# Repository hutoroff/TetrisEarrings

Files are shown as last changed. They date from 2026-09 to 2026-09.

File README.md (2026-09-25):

# ✨ TetrisEarrings

Earrings built on a 6×10 LED matrix with nine mesmerizing animated modes — from ping-pong and Tetris with an autonomous bot to fire, a starry sky, and rain on glass.







<p align="center">
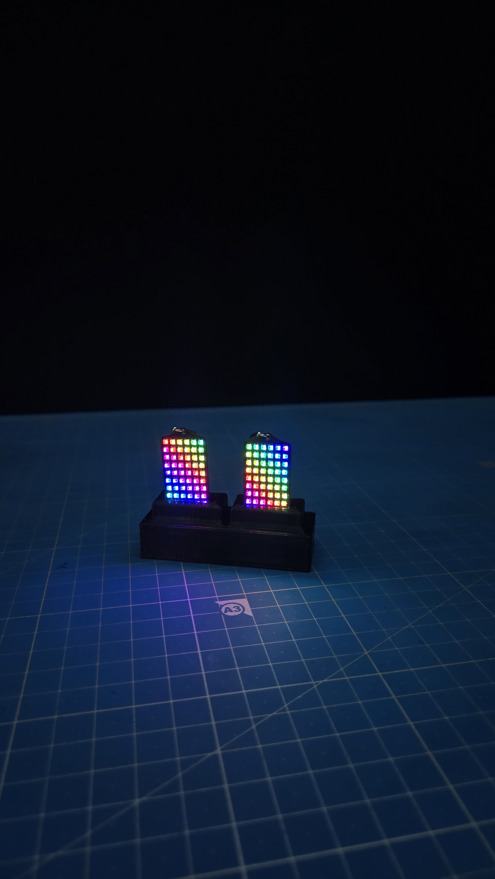
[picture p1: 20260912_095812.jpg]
TetrisEarrings in action
  
</p>

## About

A tiny STM32 board hidden inside the earring drives a matrix of 60 addressable RGB LEDs (6 columns × 10 rows). A single button switches modes manually, or they cycle on their own every 45 seconds. The device runs on a battery and can power itself off — either on a long button press or when the battery runs low — with a short farewell animation.

## Features

- 🎮 **9 modes** — from classic games to generative visual effects
- 🧠 **Tetris with a "smart" bot** — pieces don't just fall randomly: before each drop the bot tries every rotation and column and picks the placement using a heuristic (fewest holes, lowest height and bumpiness, most cleared lines)
- 🐍 **Snake with an autonomous bot** — finds its own path to the food and never runs into itself
- 🎨 **Sub-pixel smoothing** — the ping-pong balls move smoothly instead of jumping from LED to LED
- 🔋 **Smart power management** — continuous battery voltage monitoring and automatic shutdown on low battery
- 📺 **Power-off animation** — the screen "collapses" into a dot and fades out, like an old CRT TV
- 🧩 **Everything in 6 KB of RAM** — all modes share the same memory region (a union) instead of each mode keeping its own data

## Modes

| # | Mode | Description |
|---|---|---|
| 0 | Ping-Pong | Three balls fly around and bounce off each other, changing color on impact |
| 1 | Tetris | Autonomous game with a bot that deliberately chooses where to place each piece |
| 2 | Snake | Autonomous game; the bot steers the snake to the food by itself |
| 3 | Heart | A smoothly pulsing heart |
| 4 | Fire | Procedural simulation of a living flame with sparks |
| 5 | Matrix | Falling green "digital rain" in the style of *The Matrix* |
| 6 | Starry Sky | Sparse twinkling stars of different hues that slowly fade out |
| 7 | Rainbow | A shimmering diagonal rainbow wave |
| 8 | Rain on Glass | Drops trickle down and burst into splashes when they hit the bottom |

Short button press — next mode; hold for about a second — power off (with animation). With no presses, modes cycle automatically every 45 seconds.

## Hardware

| Parameter | Value |
|---|---|
| Microcontroller | STM32F070F6Px (Cortex-M0, 48 MHz, 32 KB Flash, 6 KB RAM) |
| Matrix | 6×10 (60 pcs) addressable RGB LEDs, WS2812-compatible protocol |
| Matrix data line | PA9 (TIM1_CH2 + DMA, per-bit PWM signal encoding) |
| Button | PA7 |
| Power control | PA6 (board power self-latch / shutdown) |
| Battery monitoring | PA1 (ADC1_IN1), auto-shutdown on low battery |
| Development environment | STM32CubeIDE 1.17.0, GNU Arm Embedded Toolchain 12.3.rel1 |

The matrix LEDs are wired in a "serpentine" layout: even rows run in one direction, odd rows in the other (see `GetLEDIndex()` in [ledMatrix.c](Core/Src/ledMatrix.c)).

### Power

1S Li-Po → P-MOSFET soft latch (button turns it on, PA6 holds it, PA6 low = off) → switched rail `VSW`. The LEDs run straight from `VSW` (3.5–4.2 V); the MCU gets 3.3 V from an LDO. Battery voltage is sensed on PA1 through a 62k/100k divider, so the firmware's 2700-count threshold means a **3.52 V** cutoff. Charging: MCP73831 at ~150 mA from two dock pads (the printed stand). Average draw ≈ 55–60 mA (mostly WS2812 idle current), so a 300 mAh 602030 cell gives ≈ 4.5 h.

### Components

| Qty | Ref | Part | Package | Note |
|---|---|---|---|---|
| 1 | U1 | STM32F070F6P6 | TSSOP-20 | MCU |
| 60 | LED1–LED60 | WS2812B-2020 | 2020 PLCC-4 | 6×10 matrix |
| 1 | U2 | MCP73831T-2ACI/OT | SOT-23-5 | Li-Po charger 4.2 V |
| 1 | U3 | ME6211C33M5G | SOT-23 | 3.3 V LDO |
| 1 | Q1 | AO3401A | SOT-23 | P-MOSFET power switch |
| 1 | Q2 | 2N7002 | SOT-23 | Latch driver |
| 2 | D1, D2 | BAT54W | SOD-323 | Latch OR diodes |
| 1 | D3 | LED red | 0603 | Charge indicator |
| 1 | Y1 | 8 MHz crystal | 3225 | HSE |
| 1 | SW1 | Tactile switch | SMD | Mode / power button |
| 1 | BT1 | Li-Po 1S 602030 300 mAh | 2 pads | With PCM; 602535 400 mAh for more runtime |
| — | J1 | TC2030-IDC-NL footprint | Tag-Connect pads | SWD; bare copper, nothing to buy |
| — | J2 | Dock contacts | 2 pads | 5 V charging; bare copper, nothing to buy |
| 5 | R1, R2, R3, R5, R8 | 100k | 0402 | Pull-ups/downs, dividers |
| 1 | R4 | 33k | 0402 | Button divider |
| 1 | R6 | 330 Ω | 0402 | LED data series |
| 1 | R7 | 62k | 0402 | Battery divider (cutoff) |
| 1 | R9 | 6.8k | 0402 | Charge current |
| 1 | R10 | 1k | 0402 | Charge LED |
| 1 | R11 | 10k | 0402 | BOOT0 |
| 13 | C5, C7, C8, C13–C22 | 100 nF | 0402 | Decoupling, NRST, LED rows |
| 3 | C3, C4, C6 | 1 µF | 0402 | LDO in/out, VDD |
| 2 | C9, C10 | 12 pF | 0402 | Crystal load |
| 1 | C11 | 10 nF | 0402 | ADC filter |
| 2 | C1, C2 | 4.7 µF | 0603 | Charger in/out |
| 1 | C12 | 10 µF | 0603 | LED rail bulk |

Total: 104 purchased components (24 BOM lines) plus 2 copper-pad footprints. Machine-readable list: [hardware/BOM.csv](hardware/BOM.csv).

## Electronics (Altium)

Schematic, PCB and BOM live in [`hardware/`](hardware/) as a KiCad project (text, generated by `gen_schematic.py` / `gen_pcb.py`). The PCB is 24 × 48 mm, 4 layers: the LEDs are on the front, everything else is on the back, and the inner layers are GND and VSW planes. It is fully routed, with DRC 0 errors and 0 differences from the schematic. Ready-to-upload JLCPCB files are in [`hardware/fab/`](hardware/fab/).

Altium Designer 21+ opens it directly: **File → Import Wizard → KiCad Design Files** → select the `hardware/` folder → Finish → **Project → Compile**. Circuit description, layout notes and tuning knobs (battery cutoff, charge current, battery size) are in [hardware/README.md](hardware/README.md).

## Building and Flashing

1. Clone the repository and open the project folder in **STM32CubeIDE 1.17.0** (File → Import → General → Existing Projects into Workspace).
2. Choose a build configuration:
   - **Debug** — full debug symbols, `-Og` optimization (chosen specifically so the firmware fits into the chip's 32 KB of flash while still being easy to debug);
   - **Release** — `-Os` build, minimal size.
3. **Project → Build Project**.
4. Flash via ST-Link: **Run → Debug** (or **Run**) with the programmer connected.

## Project Structure

```
Core/
├── Inc/                  # Headers
│   ├── effects.h          # Visual effects
│   ├── games.h            # Tetris and Snake
│   ├── ledMatrix.h        # WS2812 driver
│   └── saportAndData.h    # Shared state (pins, shared mode memory)
└── Src/
    ├── main.c              # Entry point, peripheral initialization
    ├── work.c               # Mode dispatcher, button, ADC, auto-shutdown
    ├── effects.c             # Ping-Pong, Fire, Matrix, Stars, Rainbow, Rain, Heart
    ├── games.c               # Tetris (with AI bot) and Snake (with autonomous bot)
    └── ledMatrix.c            # Addressable matrix driver on top of TIM1 + DMA
```

## License

This project is distributed under the [MIT](LICENSE) license.

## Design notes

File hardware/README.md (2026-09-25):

# TetrisEarrings — electronics

KiCad project generated by scripts; Altium Designer imports it natively.

| File | What |
|---|---|
| `TetrisEarrings.kicad_sch` / `.kicad_pro` | Schematic (single A2 sheet, all symbols embedded) |
| `TetrisEarrings.kicad_pcb` | PCB, 24 × 48 × 0.8 mm, 4 layers, fully routed |
| `TetrisEarrings.pretty/`, `fp-lib-table`, `sym-lib-table`, `.kicad_sym` | Project libraries (the two pad footprints; everything else is KiCad stock) |
| `BOM.csv` | Bill of materials, grouped by value/package |
| `fab/` | JLCPCB upload: Gerber+drill zip, BOM, CPL (pick-and-place) |
| `gen_schematic.py` | Schematic + BOM generator (Python 3, stdlib) |
| `gen_pcb.py` | Placement, fixed front copper, plane fanout (Python 3 + KiCad footprint libs) |
| `route.py` | Autorouting of the back-side signals with Freerouting (run with KiCad's Python) |
| `export_fab.py` | Gerbers, drill, BOM, CPL → `fab/` |

## Regenerate

```sh
python3 hardware/gen_schematic.py        # schematic + BOM
python3 hardware/gen_pcb.py              # board: placement, LED copper, fanout vias (unrouted signals)
/Applications/KiCad/KiCad.app/Contents/Frameworks/Python.framework/Versions/Current/bin/python3 hardware/route.py
python3 hardware/export_fab.py           # fab/ outputs
kicad-cli pcb drc --refill-zones --schematic-parity hardware/TetrisEarrings.kicad_pcb
```

`route.py` needs Java 17+ and `freerouting-1.9.0.jar` in `~/.cache/freerouting/fr-1.9.0.jar` (github.com/freerouting/freerouting/releases). A small Freerouting window appears while it routes. Freerouting 2.x ignores the pass limit in headless mode and never saves its result. Hand edits made in KiCad/Altium are lost on regeneration: either keep changing the scripts, or stop regenerating and treat the `.kicad_pcb` as the source from then on.

## Open in Altium Designer

1. **File → Import Wizard → KiCad Design Files** (Altium 21 or newer).
2. Add the `hardware/` folder (or the `.kicad_pro`), Next through the defaults, Finish.
3. Altium creates `TetrisEarrings.PrjPcb` with one `.SchDoc`. Run **Project → Compile** — it should report no errors; the sheet uses power ports and net labels on pin stubs, which the importer maps 1:1.
4. Optional: `kicad-cli sch export pdf TetrisEarrings.kicad_sch` for a PDF, or open in free KiCad.

## Circuit

**Power.** 1S Li-Po (602030, 300 mAh, with PCM) → `VBAT`. P-MOSFET Q1 (AO3401A) is the high-side switch producing the switched rail `VSW`, which feeds the LEDs directly (3.5–4.2 V, inside WS2812B-2020 spec) and the 3.3 V LDO U3 (ME6211) for the MCU.

**Soft latch** (matches `work.c`). Q1 gate is pulled to `VBAT` by R1 (off). Q2 (2N7002) pulls it low when `LATCH` is high; `LATCH` is the OR of the button (`KEY` via D1) and PA6 (`PWR_ON` via D2), R2 pull-down. Sequence: press → Q2 → Q1 → LDO → MCU boots, reads the button HIGH, sets PA6 = 1 → latch holds after release. PA6 = 0 (long press or low battery) → power drops; firmware spins in `while(1)` waiting for it.

**Button.** SW1 between `VBAT` and `KEY`, R3 100k pull-down (PA7 has no internal pull, pressed = HIGH). `KEY` → PA7 through R4 33k / R5 100k = 0.75·VBAT: 3.16 V at 4.2 V (≤ VDDA + 0.3), 2.6 V at 3.5 V (≥ 0.7·VDD).

**Battery sense.** R7 62k / R8 100k from `VSW` to PA1 (ADC_IN1), C11 filter. Firmware cutoff is 2700/4096 · 3.3 V = 2.175 V → **3.52 V** battery. On `VSW`, so no drain when off. Tune R7: 68k → 3.65 V, 56k → 3.39 V.

**Charger.** MCP73831-2 (4.2 V), input from two dock pads J2 (`VCHG` 5 V, GND — the printed stand acts as the dock), R9 6.8k → ~150 mA (0.5 C), D3 charge indicator. The charger connects straight to the battery, so charging works with the earring off.

**LEDs.** 60 × WS2812B-2020, DIN of LED1 from PA9 (TIM1_CH2) via R6 330 Ω. Chain order equals the firmware index from `GetLEDIndex()`: row 0 is the bottom row, even rows run right→left, odd rows left→right; LED*n* has index *n*−1. C12 10 µF bulk plus one 100 nF per row (C13–C22).

**MCU.** STM32F070F6P6 TSSOP-20, 8 MHz crystal Y1 with 12 pF loads (`ponytail:` set to the crystal's CL), BOOT0 10k to GND, NRST 100 nF, SWD via Tag-Connect TC2030 pads (J1). PA0, PA2–PA5, PA10, PB1 unused; PA3/PA4 (`Led1`/`Led2` in the `.ioc`) are initialised by firmware but never driven, so they are left unconnected.

## PCB layout

**Stackup** (JLC 4-layer, 0.8 mm):

| Layer | Contents |
|---|---|
| F.Cu | LEDs, data chain, power rails |
| In1 | GND plane |
| In2 | VSW plane |
| B.Cu | all other parts and signal routing |

The rules are the JLC standard: 0.15 mm track and clearance, 0.45/0.2 mm vias, 0.3 mm copper-to-edge.

**Front (jewellery face).**
- The LEDs sit on a 3.5 mm grid, and odd rows are rotated 180° so each DOUT→DIN hop is a short jog.
- Each gap between rows carries one power rail, alternating VSW and GND. Each rail hugs the row below it, which leaves a band where signal vias fit.
- The rails reach the planes only through vias in the board-edge strips (GND on the left, VSW on the right). This keeps the back free of a via grid.
- There is no silkscreen on the front, and there are 2 dock pads at the bottom edge.

**Back.**
- MCU in the middle, with the crystal right against PF0/PF1.
- Soft-latch parts near the top, and the button at the top edge so it stays accessible.
- Charger at the bottom, next to the Tag-Connect footprint (it has 3 NPTH alignment holes).
- Battery pads on the left edge. Glue the 602030 pouch over the back parts with kapton tape in between; the button and SWD pads stay uncovered.
- Every back-side GND/VSW pad has its own fanout via to its plane.
- 0.8 mm earring-hook hole at the top.

**Assembly.**
- JLC assembles both sides from `fab/`.
- BT1 is excluded from the CPL; solder the pouch tabs by hand.
- J1/J2 are bare copper.
- JLC's CPL preview sometimes shows parts rotated (a known library-orientation quirk, typically on SOT-23 and TSSOP). Check the rotation preview on the order page before paying.

## Power budget / battery choice

WS2812B-2020 idle current ≈ 0.6–0.7 mA each → ~40 mA for 60 LEDs, MCU ≈ 8 mA, lit-LED average ≈ 8 mA (effects stay ≤ ~25 % per channel) → **≈ 55–60 mA**. 300 mAh usable to 3.5 V ≈ 4.5 h. For more margin use 602535 (400 mAh, ≈ 6 h) — same pads, BOM change only.

Footprints `TetrisEarrings:Pad_Battery_2x` and `Pad_Dock_2x` are placeholders for two solder pads each; draw them to the pad/contact geometry of your dock.

## Verification (KiCad 10.0.6)

- `kicad-cli sch erc`: 0 errors, 0 warnings.
- `kicad-cli pcb drc --refill-zones --schematic-parity`: 0 errors, 0 unconnected items, 0 schematic-parity issues.
- The only warnings are 61 "footprint differs from library":
  - 60 are the LEDs, whose front silkscreen was removed on purpose.
  - 1 is the Tag-Connect footprint mirrored to the back.
- `TetrisEarrings.pdf` is the rendered schematic.

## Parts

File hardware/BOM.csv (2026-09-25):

Refs | Qty | Value | Package | MPN | Description
BT1 | 1 | LiPo 300mAh | Pad_Battery_2x |  | 1S Li-Po 602030 (6x20x30 mm) with PCM, solder pads
C1, C2 | 2 | 4.7u | C_0603_1608Metric |  | Charger input; Charger output / battery
C3, C4, C6 | 3 | 1u | C_0402_1005Metric |  | LDO input; LDO output; VDD bulk
C5, C7, C8, C13, C14, C15, C16, C17, C18, C19, C20, C21, C22 | 13 | 100n | C_0402_1005Metric |  | VDD decoupling; VDDA decoupling; NRST filter; LED row decoupling
C9, C10 | 2 | 12p | C_0402_1005Metric |  | Crystal load
C11 | 1 | 10n | C_0402_1005Metric |  | ADC filter
C12 | 1 | 10u | C_0603_1608Metric |  | LED rail bulk
D1, D2 | 2 | BAT54 | D_SOD-323 | BAT54W | Button -> latch OR; PA6 -> latch OR
D3 | 1 | RED | LED_0603_1608Metric |  | Charging indicator
LED1-LED60 | 60 | WS2812B-2020 | LED_WS2812B-2020_PLCC4_2.0x2.0mm | WS2812B-2020 | Addressable RGB LED 2x2 mm
Q1 | 1 | AO3401A | SOT-23 | AO3401A | High-side P-MOSFET switch
Q2 | 1 | 2N7002 | SOT-23 | 2N7002 | Latch driver
R1, R2, R3, R5, R8 | 5 | 100k | R_0402_1005Metric |  | Q1 gate pull-up (off); Latch pull-down; Button pull-down; Battery divider bottom; Button divider bottom
R4 | 1 | 33k | R_0402_1005Metric |  | Button divider top
R6 | 1 | 330 | R_0402_1005Metric |  | LED data series
R7 | 1 | 62k | R_0402_1005Metric |  | Battery divider top (sets 3.52 V cutoff)
R9 | 1 | 6.8k | R_0402_1005Metric |  | Charge current 1000V/R = 147 mA
R10 | 1 | 1k | R_0402_1005Metric |  | Charge LED series
R11 | 1 | 10k | R_0402_1005Metric |  | BOOT0 pull-down
SW1 | 1 | BTN | SW_Push_1P1T_NO_CK_KMR2 |  | Tactile button (mode / power)
U1 | 1 | STM32F070F6P6 | TSSOP-20_4.4x6.5mm_P0.65mm | STM32F070F6P6 | Cortex-M0 MCU, TSSOP-20
U2 | 1 | MCP73831-2 | SOT-23-5 | MCP73831T-2ACI/OT | Li-Po charger 4.2 V, ~150 mA
U3 | 1 | ME6211C33 | SOT-23 | ME6211C33M5G-N | 3.3 V LDO, low dropout
Y1 | 1 | 8MHz | Crystal_SMD_3225-4Pin_3.2x2.5mm |  | HSE 8 MHz, 3225

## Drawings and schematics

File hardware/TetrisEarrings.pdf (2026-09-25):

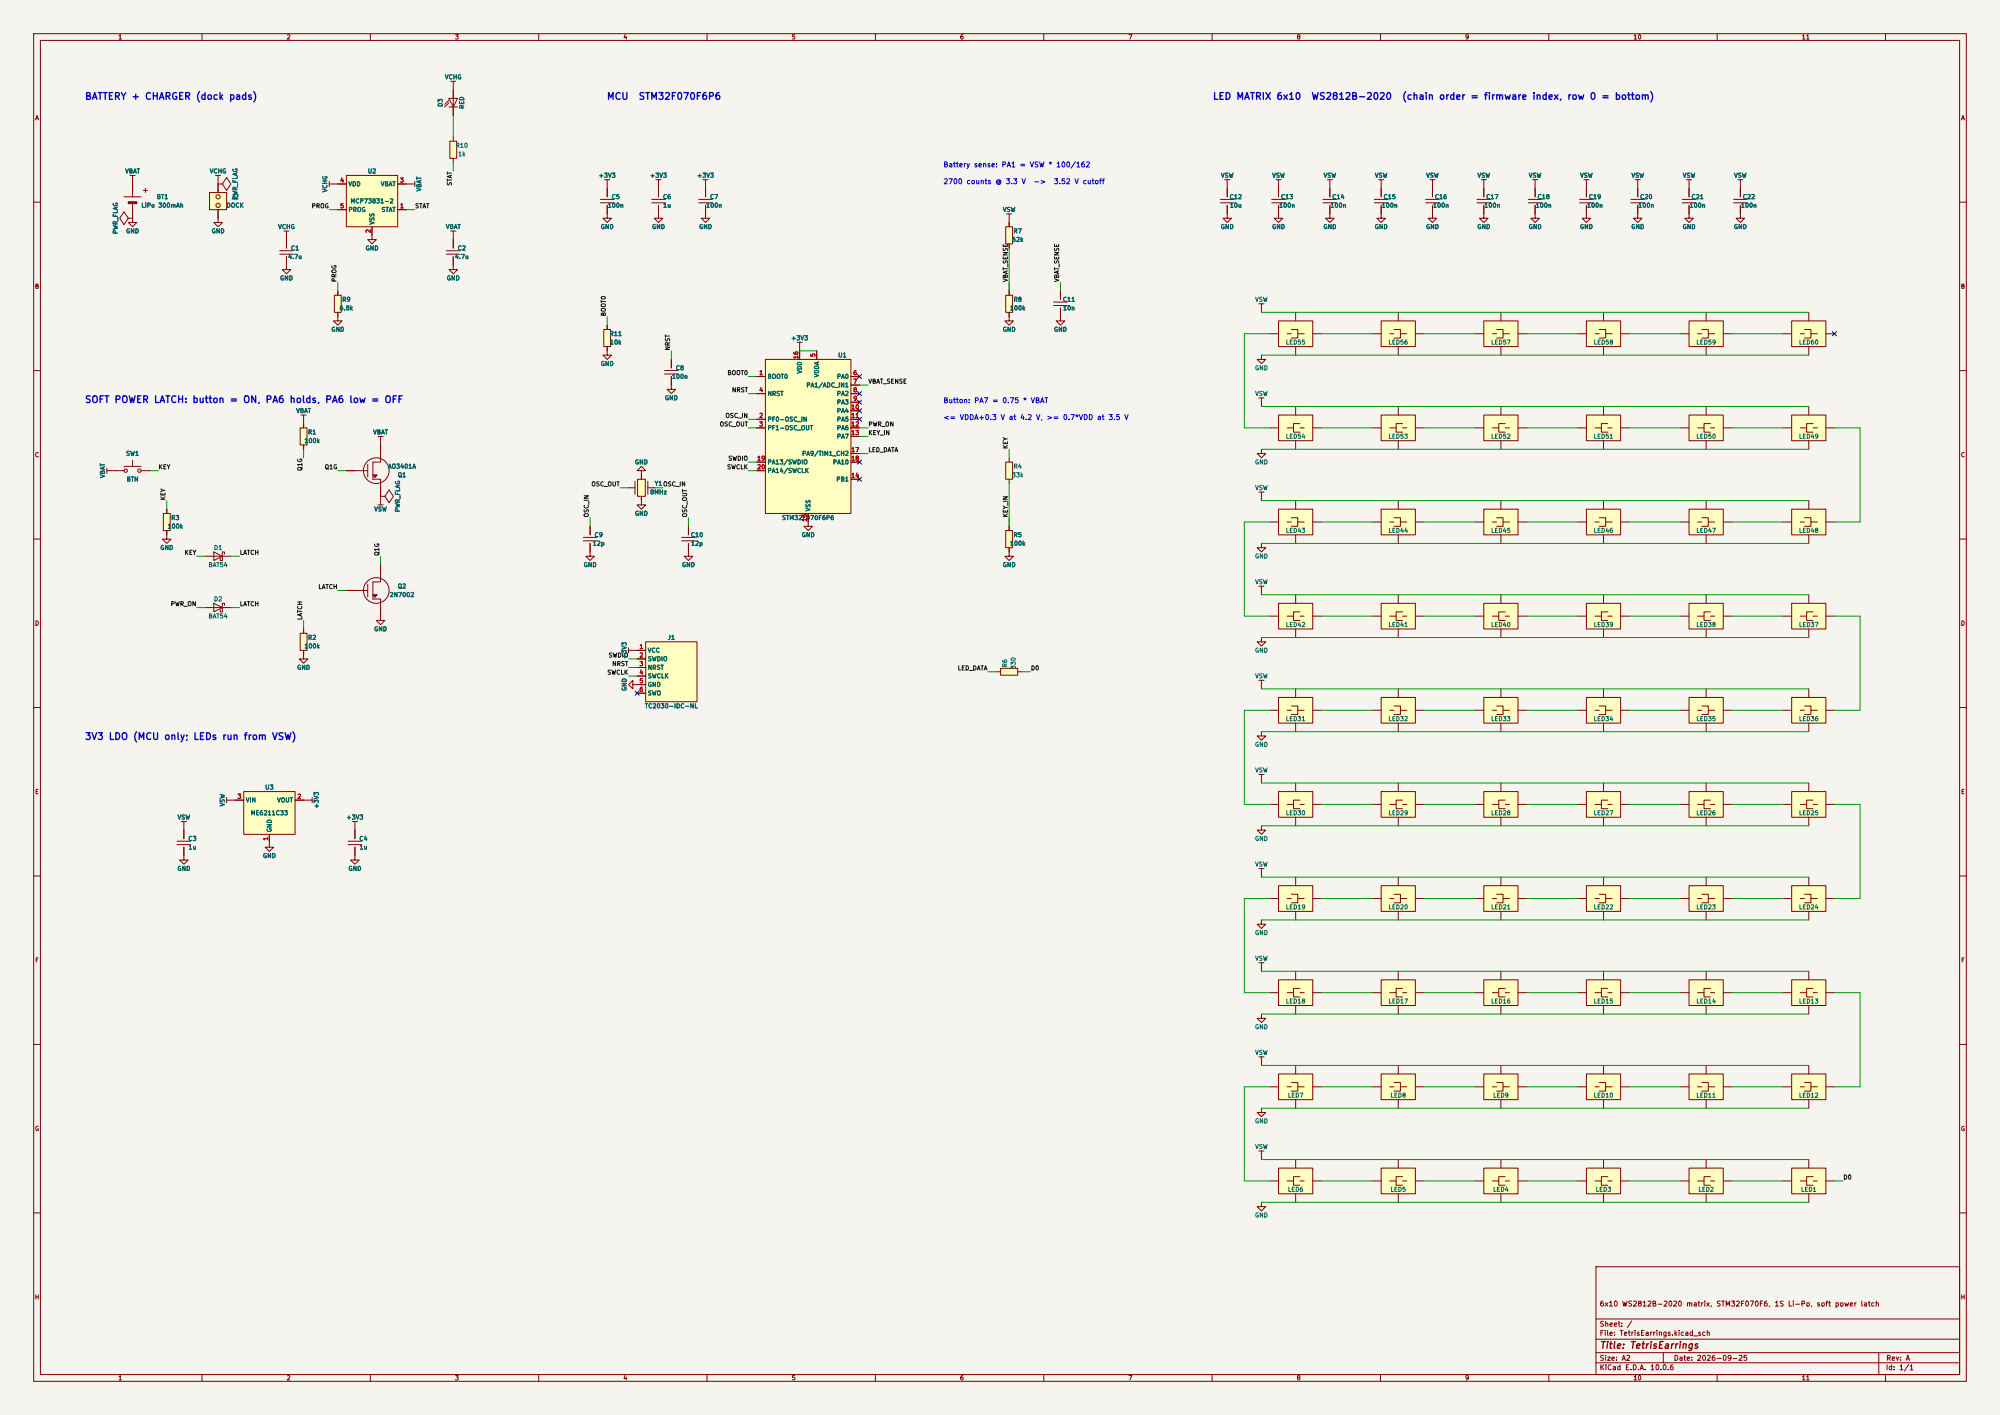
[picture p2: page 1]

SOFT POWER LATCH: button = ON, PA6 holds, PA6 low = OFF

6x10 WS2812B-2020 matrix, STM32F070F6, 1S Li-Po, soft power latch

Size: A2 | Rev: A
KiCad E.D.A. 10.0.6 | Id: 1/1

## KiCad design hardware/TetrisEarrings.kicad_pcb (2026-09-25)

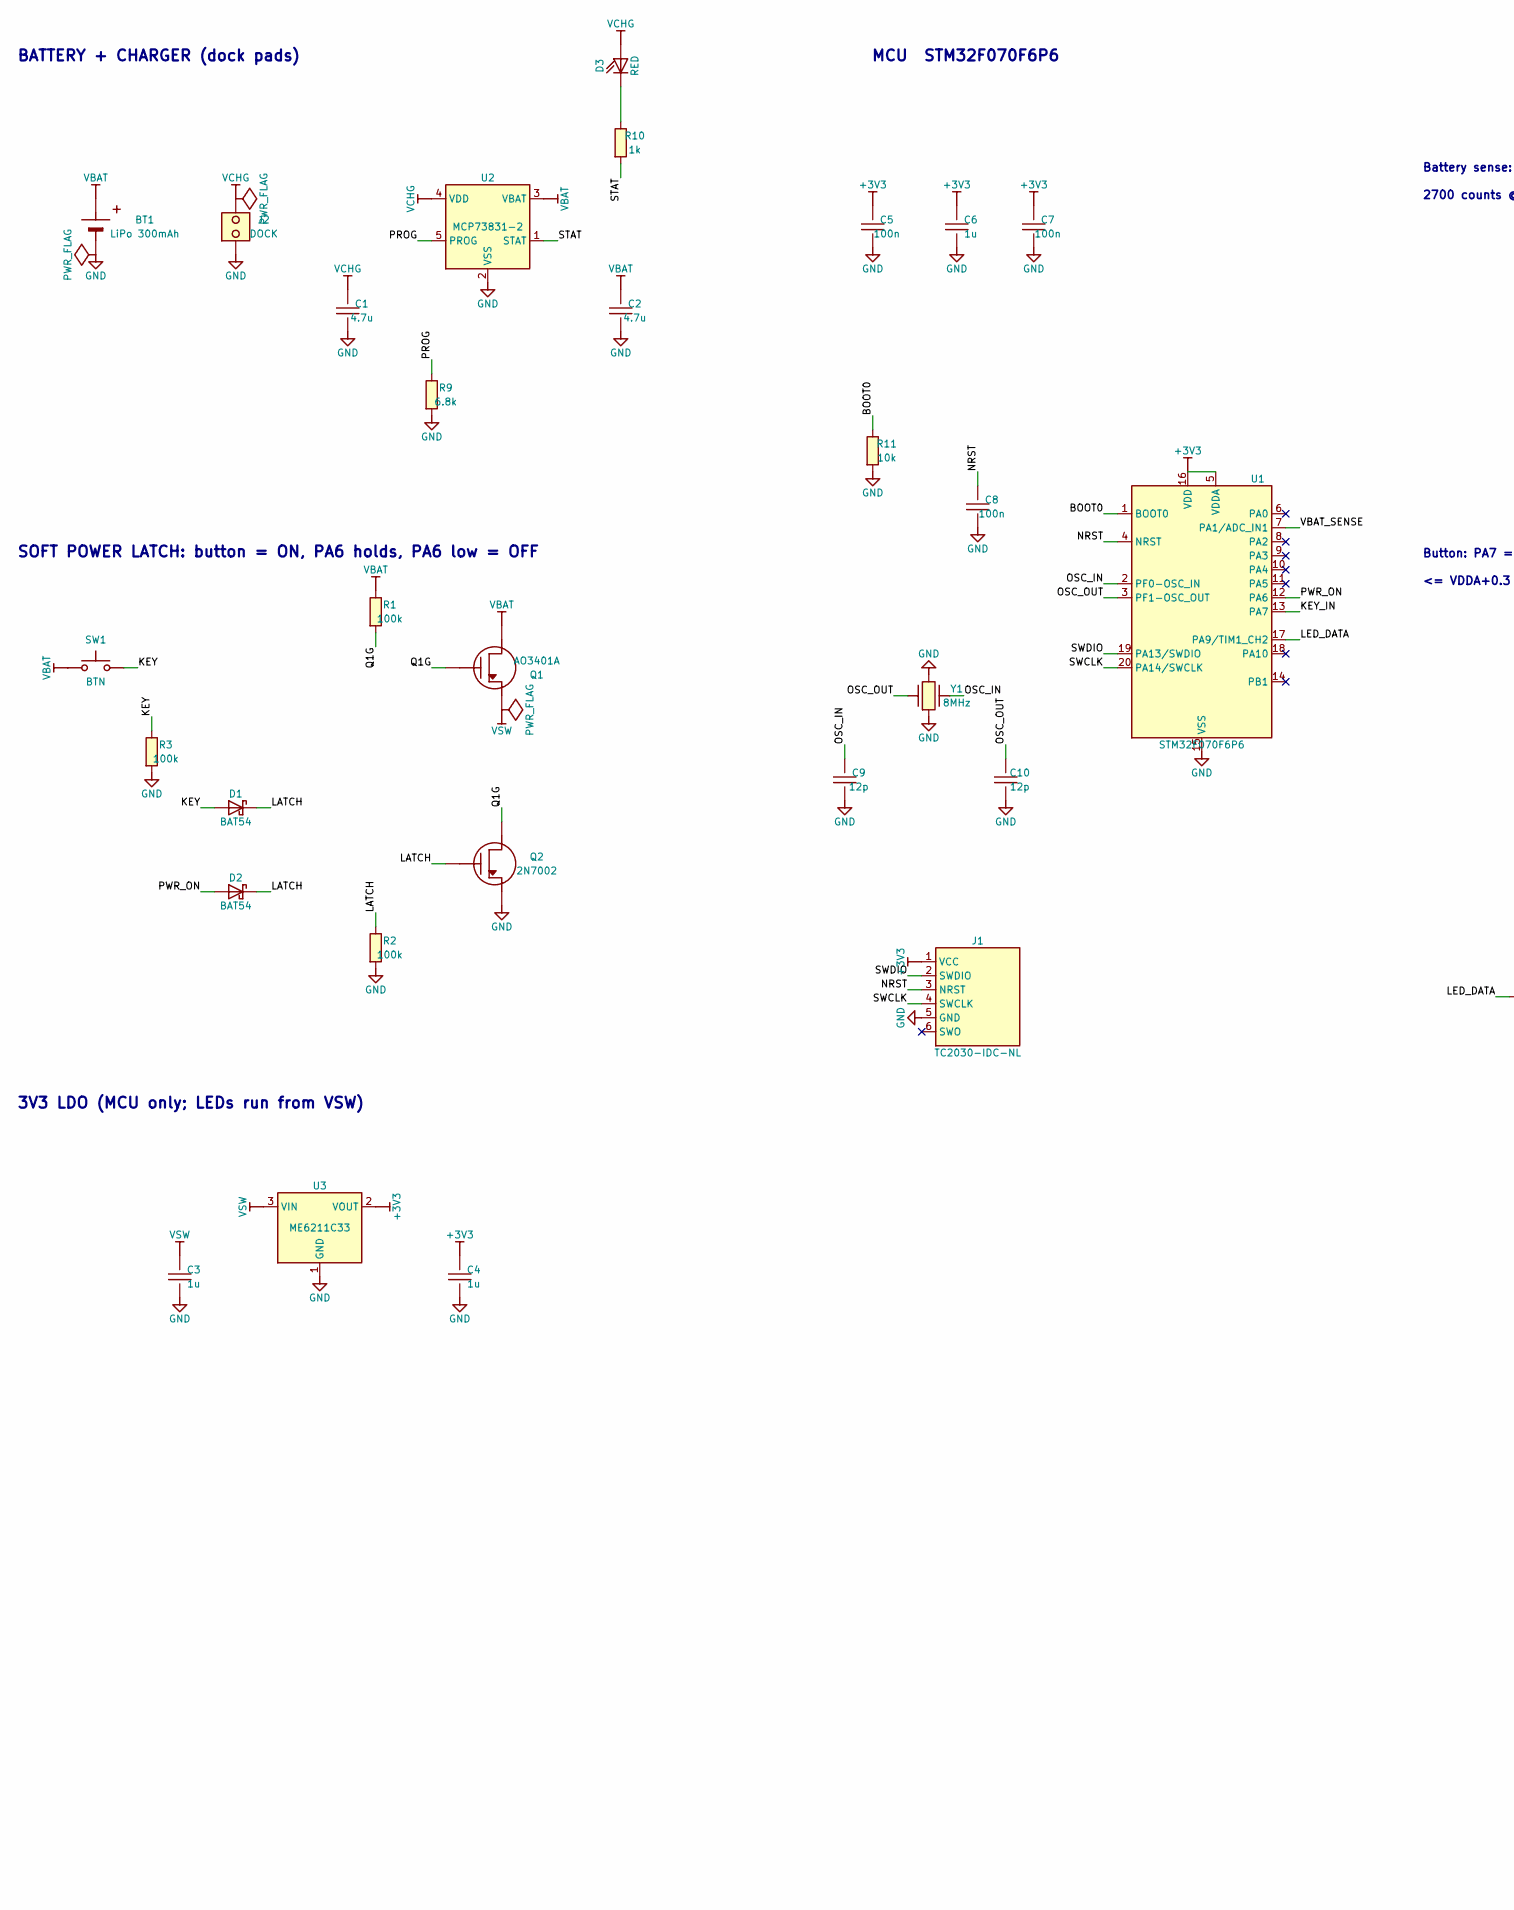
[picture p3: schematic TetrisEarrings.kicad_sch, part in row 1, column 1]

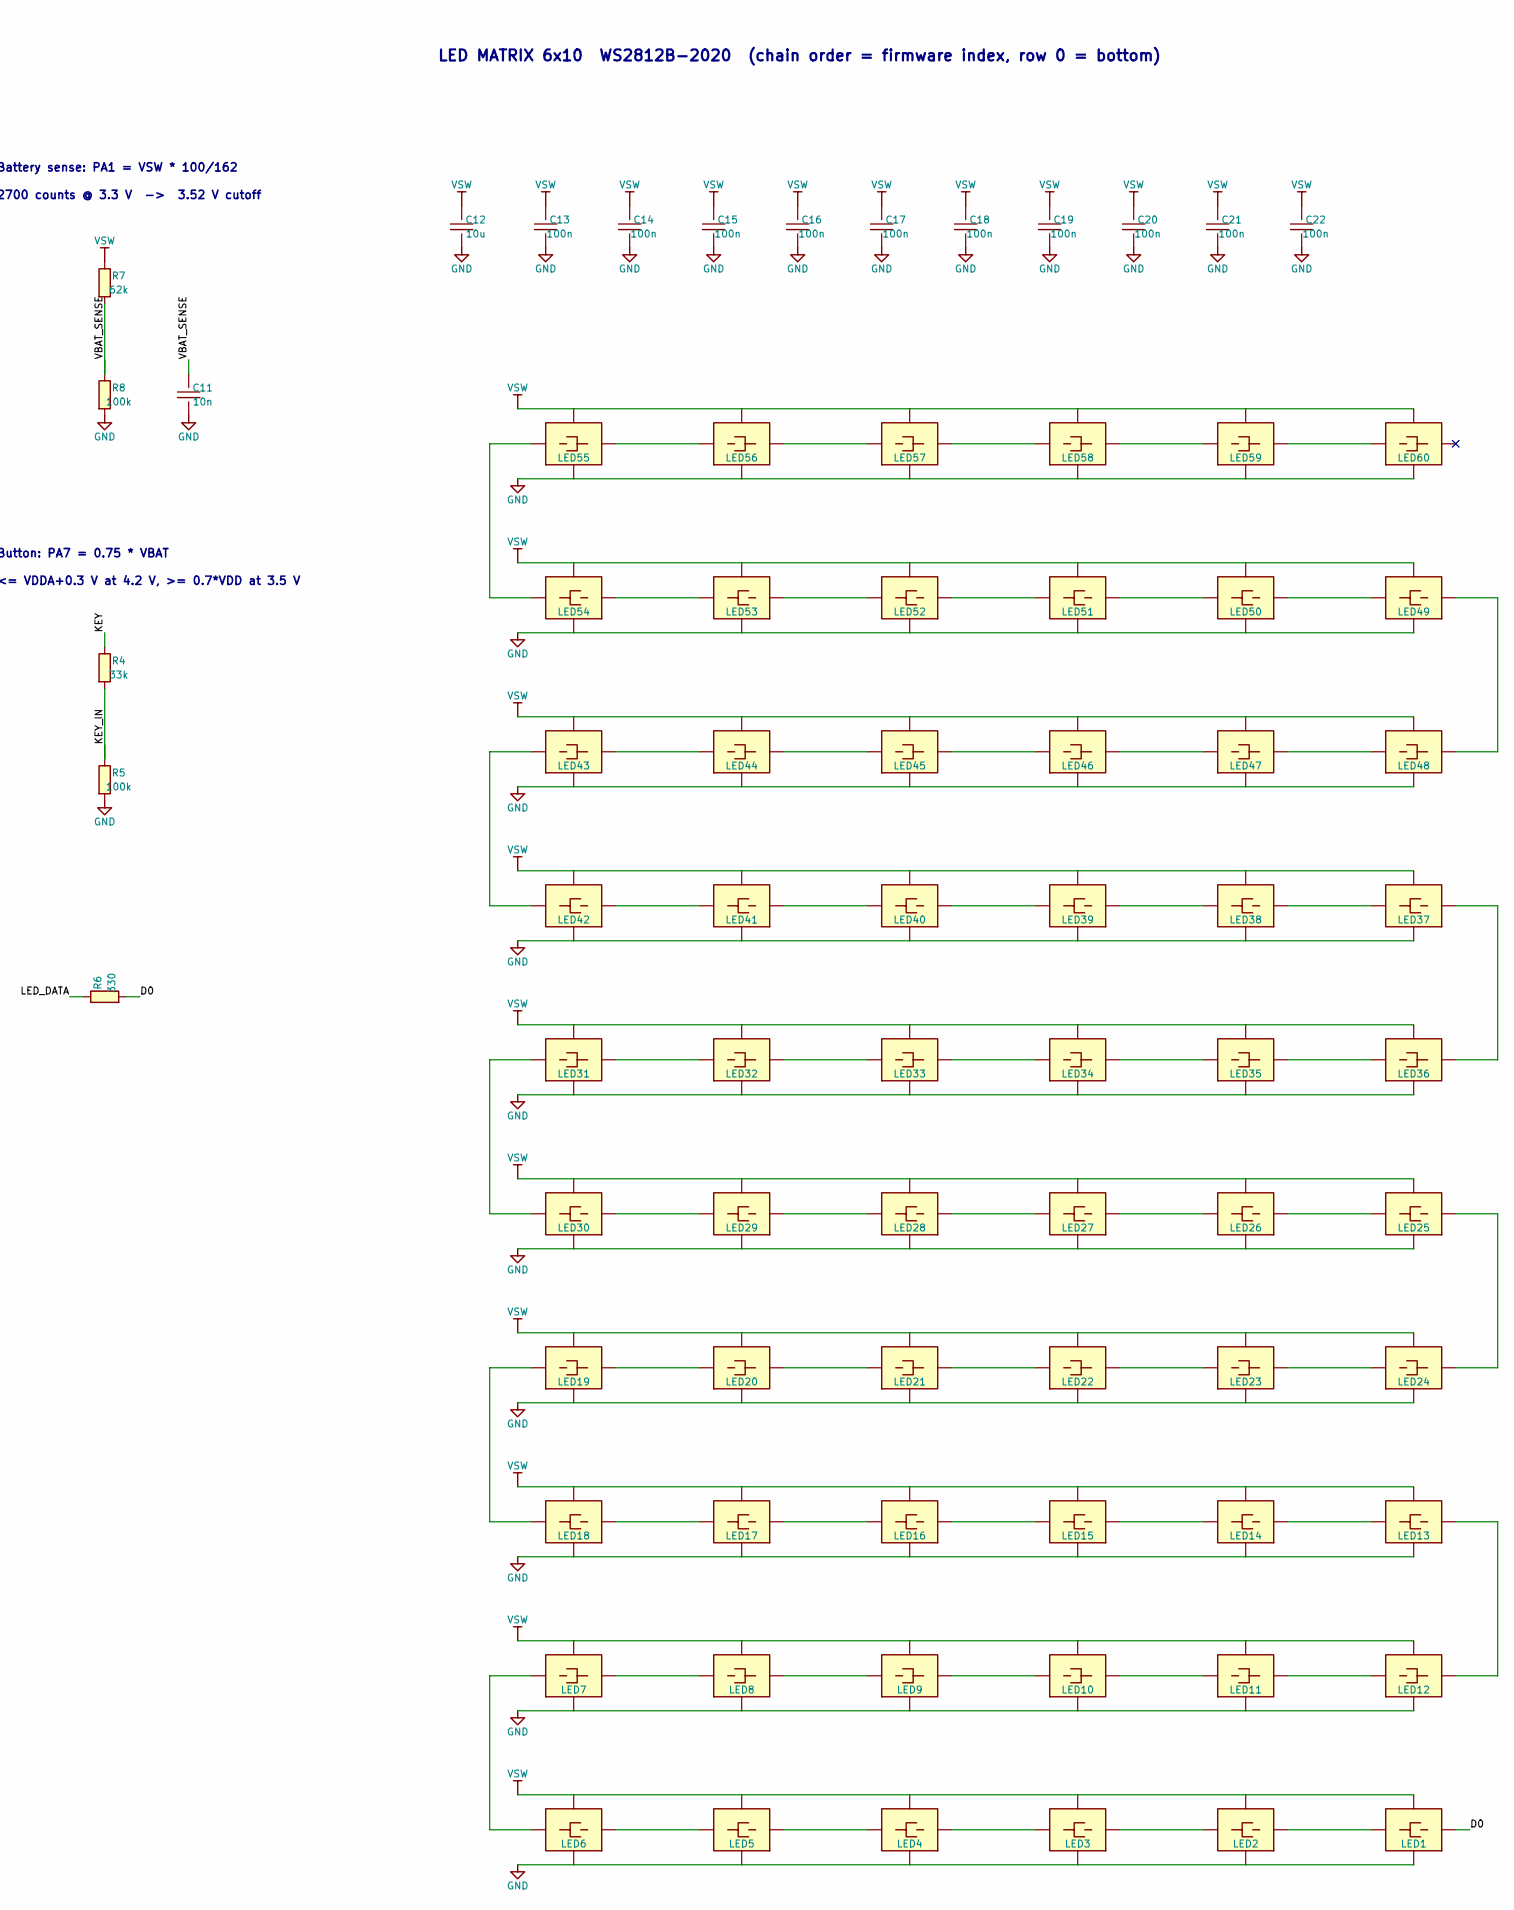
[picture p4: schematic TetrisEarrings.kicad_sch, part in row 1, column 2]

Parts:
BT1: LiPo 300mAh; Pad_Battery_2x
C1, C2: 4.7u; C_0603_1608Metric
C3, C4, C6: 1u; C_0402_1005Metric
C5, C7, C8, C13, C14, C15, C16, C17, C18, C19, C20, C21, C22: 100n; C_0402_1005Metric
C9, C10: 12p; C_0402_1005Metric
C11: 10n; C_0402_1005Metric
C12: 10u; C_0603_1608Metric
D1, D2: BAT54; D_SOD-323; MPN BAT54W
D3: RED; LED_0603_1608Metric
J1: TC2030-IDC-NL; Tag-Connect_TC2030-IDC-NL_2x03_P1.27mm_Vertical
J2: DOCK; Pad_Dock_2x
LED1, LED2, LED3, LED4, LED5, LED6, LED7, LED8, LED9, LED10, LED11, LED12, LED13, LED14, LED15, LED16, LED17, LED18, LED19, LED20, LED21, LED22, LED23, LED24, LED25, LED26, LED27, LED28, LED29, LED30, LED31, LED32, LED33, LED34, LED35, LED36, LED37, LED38, LED39, LED40, LED41, LED42, LED43, LED44, LED45, LED46, LED47, LED48, LED49, LED50, LED51, LED52, LED53, LED54, LED55, LED56, LED57, LED58, LED59, LED60: WS2812B-2020; LED_WS2812B-2020_PLCC4_2.0x2.0mm; MPN WS2812B-2020
Q1: AO3401A; SOT-23; MPN AO3401A
Q2: 2N7002; SOT-23; MPN 2N7002
R1, R2, R3, R5, R8: 100k; R_0402_1005Metric
R4: 33k; R_0402_1005Metric
R6: 330; R_0402_1005Metric
R7: 62k; R_0402_1005Metric
R9: 6.8k; R_0402_1005Metric
R10: 1k; R_0402_1005Metric
R11: 10k; R_0402_1005Metric
SW1: BTN; SW_Push_1P1T_NO_CK_KMR2
U1: STM32F070F6P6; TSSOP-20_4.4x6.5mm_P0.65mm; MPN STM32F070F6P6
U2: MCP73831-2; SOT-23-5; MPN MCP73831T-2ACI/OT
U3: ME6211C33; SOT-23; MPN ME6211C33M5G-N
Y1: 8MHz; Crystal_SMD_3225-4Pin_3.2x2.5mm

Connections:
+3V3: C4.1, C5.1, C6.1, C7.1, J1.1 (VCC), U1.5 (VDDA), U1.16 (VDD), U3.2 (VOUT)
/BOOT0: R11.1, U1.1 (BOOT0)
/D0: LED1.4 (DIN), R6.2
/KEY: D1.2 (A), R3.1, R4.1, SW1.2
/KEY_IN: R4.2, R5.1, U1.13 (PA7)
/LATCH: D1.1 (K), D2.1 (K), Q2.1 (G), R2.1
/LED_DATA: R6.1, U1.17 (PA9/TIM1_CH2)
/NRST: C8.1, J1.3 (NRST), U1.4 (NRST)
/OSC_IN: C9.1, U1.2 (PF0-OSC_IN), Y1.3
/OSC_OUT: C10.1, U1.3 (PF1-OSC_OUT), Y1.1
/PROG: R9.1, U2.5 (PROG)
/PWR_ON: D2.2 (A), U1.12 (PA6)
/Q1G: Q1.1 (G), Q2.3 (D), R1.2
/STAT: R10.2, U2.1 (STAT)
/SWCLK: J1.4 (SWCLK), U1.20 (PA14/SWCLK)
/SWDIO: J1.2 (SWDIO), U1.19 (PA13/SWDIO)
/VBAT_SENSE: C11.1, R7.2, R8.1, U1.7 (PA1/ADC_IN1)
GND: BT1.2 (-), C1.2, C2.2, C3.2, C4.2, C5.2, C6.2, C7.2, C8.2, C9.2, C10.2, C11.2, C12.2, C13.2, C14.2, C15.2, C16.2, C17.2, C18.2, C19.2, C20.2, C21.2, C22.2, J1.5 (GND), J2.2, LED1.3 (GND), LED2.3 (GND), LED3.3 (GND), LED4.3 (GND), LED5.3 (GND), LED6.3 (GND), LED7.3 (GND), LED8.3 (GND), LED9.3 (GND), LED10.3 (GND), LED11.3 (GND), LED12.3 (GND), LED13.3 (GND), LED14.3 (GND), LED15.3 (GND), LED16.3 (GND), LED17.3 (GND), LED18.3 (GND), LED19.3 (GND), LED20.3 (GND), LED21.3 (GND), LED22.3 (GND), LED23.3 (GND), LED24.3 (GND), LED25.3 (GND), LED26.3 (GND), LED27.3 (GND), LED28.3 (GND), LED29.3 (GND), LED30.3 (GND), LED31.3 (GND), LED32.3 (GND), LED33.3 (GND), LED34.3 (GND), LED35.3 (GND), LED36.3 (GND), LED37.3 (GND), LED38.3 (GND), LED39.3 (GND), LED40.3 (GND), LED41.3 (GND), LED42.3 (GND), LED43.3 (GND), LED44.3 (GND), LED45.3 (GND), LED46.3 (GND), LED47.3 (GND), LED48.3 (GND), LED49.3 (GND), LED50.3 (GND), LED51.3 (GND), LED52.3 (GND), LED53.3 (GND), LED54.3 (GND), LED55.3 (GND), LED56.3 (GND), LED57.3 (GND), LED58.3 (GND), LED59.3 (GND), LED60.3 (GND), Q2.2 (S), R2.2, R3.2, R5.2, R8.2, R9.2, R11.2, U1.15 (VSS), U2.2 (VSS), U3.1 (GND), Y1.2 (GND), Y1.4 (GND)
unnamed: D3.1 (K), R10.1
unnamed: LED1.2 (DOUT), LED2.4 (DIN)
unnamed: LED2.2 (DOUT), LED3.4 (DIN)
unnamed: LED3.2 (DOUT), LED4.4 (DIN)
unnamed: LED4.2 (DOUT), LED5.4 (DIN)
unnamed: LED5.2 (DOUT), LED6.4 (DIN)
unnamed: LED6.2 (DOUT), LED7.4 (DIN)
unnamed: LED7.2 (DOUT), LED8.4 (DIN)
unnamed: LED8.2 (DOUT), LED9.4 (DIN)
unnamed: LED9.2 (DOUT), LED10.4 (DIN)
unnamed: LED10.2 (DOUT), LED11.4 (DIN)
unnamed: LED11.2 (DOUT), LED12.4 (DIN)
unnamed: LED12.2 (DOUT), LED13.4 (DIN)
unnamed: LED13.2 (DOUT), LED14.4 (DIN)
unnamed: LED14.2 (DOUT), LED15.4 (DIN)
unnamed: LED15.2 (DOUT), LED16.4 (DIN)
unnamed: LED16.2 (DOUT), LED17.4 (DIN)
unnamed: LED17.2 (DOUT), LED18.4 (DIN)
unnamed: LED18.2 (DOUT), LED19.4 (DIN)
unnamed: LED19.2 (DOUT), LED20.4 (DIN)
unnamed: LED20.2 (DOUT), LED21.4 (DIN)
unnamed: LED21.2 (DOUT), LED22.4 (DIN)
unnamed: LED22.2 (DOUT), LED23.4 (DIN)
unnamed: LED23.2 (DOUT), LED24.4 (DIN)
unnamed: LED24.2 (DOUT), LED25.4 (DIN)
unnamed: LED25.2 (DOUT), LED26.4 (DIN)
unnamed: LED26.2 (DOUT), LED27.4 (DIN)
unnamed: LED27.2 (DOUT), LED28.4 (DIN)
unnamed: LED28.2 (DOUT), LED29.4 (DIN)
unnamed: LED29.2 (DOUT), LED30.4 (DIN)
unnamed: LED30.2 (DOUT), LED31.4 (DIN)
unnamed: LED31.2 (DOUT), LED32.4 (DIN)
unnamed: LED32.2 (DOUT), LED33.4 (DIN)
unnamed: LED33.2 (DOUT), LED34.4 (DIN)
unnamed: LED34.2 (DOUT), LED35.4 (DIN)
unnamed: LED35.2 (DOUT), LED36.4 (DIN)
unnamed: LED36.2 (DOUT), LED37.4 (DIN)
unnamed: LED37.2 (DOUT), LED38.4 (DIN)
unnamed: LED38.2 (DOUT), LED39.4 (DIN)
unnamed: LED39.2 (DOUT), LED40.4 (DIN)
unnamed: LED40.2 (DOUT), LED41.4 (DIN)
unnamed: LED41.2 (DOUT), LED42.4 (DIN)
unnamed: LED42.2 (DOUT), LED43.4 (DIN)
unnamed: LED43.2 (DOUT), LED44.4 (DIN)
unnamed: LED44.2 (DOUT), LED45.4 (DIN)
unnamed: LED45.2 (DOUT), LED46.4 (DIN)
unnamed: LED46.2 (DOUT), LED47.4 (DIN)
unnamed: LED47.2 (DOUT), LED48.4 (DIN)
unnamed: LED48.2 (DOUT), LED49.4 (DIN)
unnamed: LED49.2 (DOUT), LED50.4 (DIN)
unnamed: LED50.2 (DOUT), LED51.4 (DIN)
unnamed: LED51.2 (DOUT), LED52.4 (DIN)
unnamed: LED52.2 (DOUT), LED53.4 (DIN)
unnamed: LED53.2 (DOUT), LED54.4 (DIN)
unnamed: LED54.2 (DOUT), LED55.4 (DIN)
unnamed: LED55.2 (DOUT), LED56.4 (DIN)
unnamed: LED56.2 (DOUT), LED57.4 (DIN)
unnamed: LED57.2 (DOUT), LED58.4 (DIN)
unnamed: LED58.2 (DOUT), LED59.4 (DIN)
unnamed: LED59.2 (DOUT), LED60.4 (DIN)
VBAT: BT1.1 (+), C2.1, Q1.2 (S), R1.1, SW1.1, U2.3 (VBAT)
VCHG: C1.1, D3.2 (A), J2.1, U2.4 (VDD)
VSW: C3.1, C12.1, C13.1, C14.1, C15.1, C16.1, C17.1, C18.1, C19.1, C20.1, C21.1, C22.1, LED1.1 (VDD), LED2.1 (VDD), LED3.1 (VDD), LED4.1 (VDD), LED5.1 (VDD), LED6.1 (VDD), LED7.1 (VDD), LED8.1 (VDD), LED9.1 (VDD), LED10.1 (VDD), LED11.1 (VDD), LED12.1 (VDD), LED13.1 (VDD), LED14.1 (VDD), LED15.1 (VDD), LED16.1 (VDD), LED17.1 (VDD), LED18.1 (VDD), LED19.1 (VDD), LED20.1 (VDD), LED21.1 (VDD), LED22.1 (VDD), LED23.1 (VDD), LED24.1 (VDD), LED25.1 (VDD), LED26.1 (VDD), LED27.1 (VDD), LED28.1 (VDD), LED29.1 (VDD), LED30.1 (VDD), LED31.1 (VDD), LED32.1 (VDD), LED33.1 (VDD), LED34.1 (VDD), LED35.1 (VDD), LED36.1 (VDD), LED37.1 (VDD), LED38.1 (VDD), LED39.1 (VDD), LED40.1 (VDD), LED41.1 (VDD), LED42.1 (VDD), LED43.1 (VDD), LED44.1 (VDD), LED45.1 (VDD), LED46.1 (VDD), LED47.1 (VDD), LED48.1 (VDD), LED49.1 (VDD), LED50.1 (VDD), LED51.1 (VDD), LED52.1 (VDD), LED53.1 (VDD), LED54.1 (VDD), LED55.1 (VDD), LED56.1 (VDD), LED57.1 (VDD), LED58.1 (VDD), LED59.1 (VDD), LED60.1 (VDD), Q1.3 (D), R7.1, U3.3 (VIN)

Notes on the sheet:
BATTERY + CHARGER (dock pads)
SOFT POWER LATCH: button = ON, PA6 holds, PA6 low = OFF
3V3 LDO (MCU only; LEDs run from VSW)
MCU STM32F070F6P6
Battery sense: PA1 = VSW * 100/162
2700 counts @ 3.3 V -> 3.52 V cutoff
Button: PA7 = 0.75 * VBAT
<= VDDA+0.3 V at 4.2 V, >= 0.7*VDD at 3.5 V
LED MATRIX 6x10 WS2812B-2020 (chain order = firmware index, row 0 = bottom)

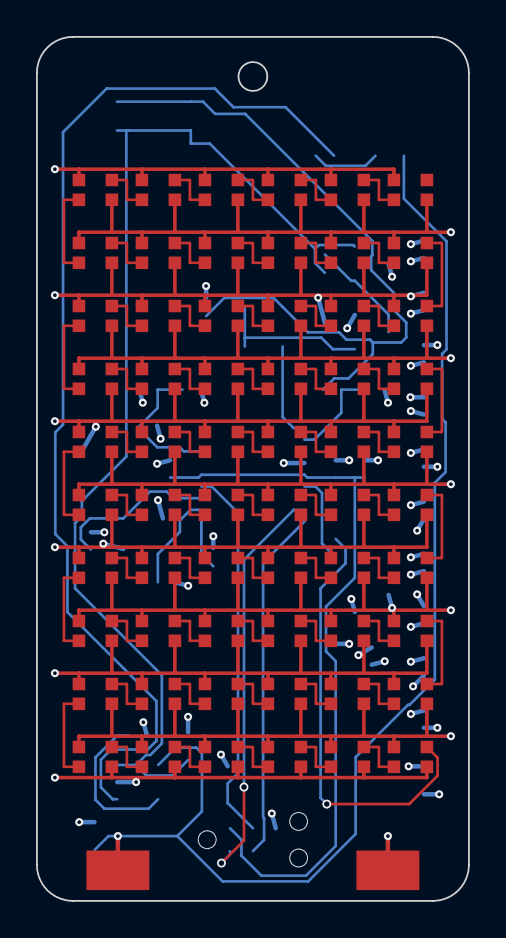
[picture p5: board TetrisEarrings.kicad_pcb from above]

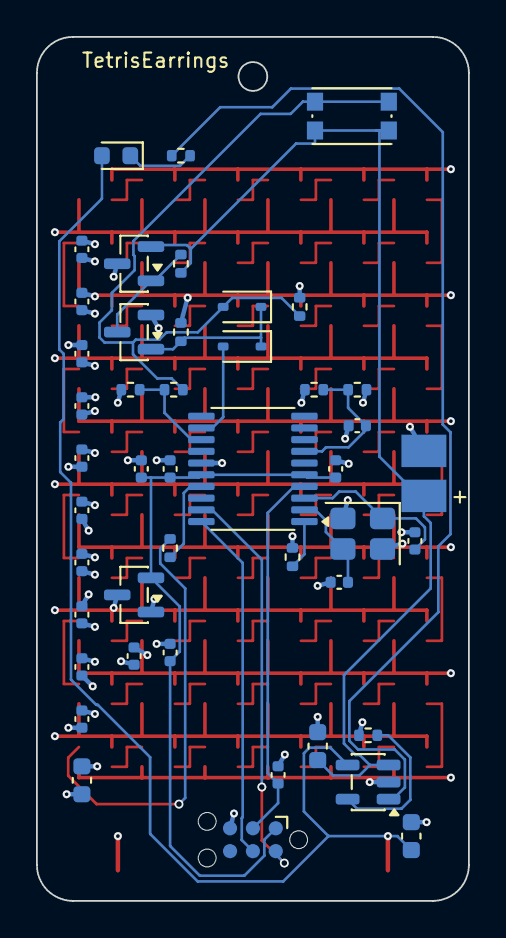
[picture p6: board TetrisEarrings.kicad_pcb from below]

Board: 4 copper layers, 24.0 x 48.0 mm, 106 parts (45 on the bottom side), 81 nets.

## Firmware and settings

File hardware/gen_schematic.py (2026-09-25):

#!/usr/bin/env python3
"""Generate TetrisEarrings.kicad_sch / .kicad_pro / BOM.csv (KiCad 8 format).

Run:  python3 hardware/gen_schematic.py
The KiCad project is the source of truth; Altium opens it via
File -> Import Wizard -> KiCad Design Files.

Connectivity is done with power symbols + net labels on short pin stubs, so the
file stays simple and survives the Altium importer.  Coordinates are mm, y down.
"""
import csv
import os
import uuid

HERE = os.path.dirname(os.path.abspath(__file__))
PROJECT = "TetrisEarrings"
ROOT_UUID = "0f8a0f60-1e7e-4a3b-9d2c-7c1e5f4b6a01"   # fixed so re-runs diff cleanly
_counter = [0]


def uid():
    # deterministic UUIDs -> stable diffs between generator runs
    _counter[0] += 1
    return str(uuid.uuid5(uuid.NAMESPACE_OID, f"{PROJECT}/{_counter[0]}"))


FONT = "(effects (font (size 1.27 1.27)))"
FONT_H = "(effects (font (size 1.27 1.27)) hide)"


# ------------------------------------------------------------------ symbols
# pins: (number, name, type, x, y, angle) in symbol space (y UP, like the lib
# files).  angle = direction from the connection point toward the body.
def pin(num, name, typ, x, y, ang, length=2.54):
    return (num, name, typ, x, y, ang, length)


def rect(x1, y1, x2, y2):
    return (f"(rectangle (start {x1} {y1}) (end {x2} {y2}) "
            f"(stroke (width 0.254) (type default)) (fill (type background)))")


def poly(*pts, fill="none"):
    p = " ".join(f"(xy {x} {y})" for x, y in pts)
    return (f"(polyline (pts {p}) (stroke (width 0.254) (type default)) "
            f"(fill (type {fill})))")


def circ(x, y, r):
    return (f"(circle (center {x} {y}) (radius {r}) "
            f"(stroke (width 0.254) (type default)) (fill (type none)))")


# Symbol definitions: name -> dict(ref, graphics, pins, value_pos, hide_pin_names)
SYMS = {}


def defsym(name, ref, graphics, pins, ref_at=(0, 0), val_at=(0, 0), names=True):
    SYMS[name] = dict(ref=ref, gfx=graphics, pins=pins, ref_at=ref_at,
                      val_at=val_at, names=names)


defsym("R", "R", [rect(-1.016, -2.54, 1.016, 2.54)],
       [pin("1", "~", "passive", 0, 3.81, 270, 1.27),
        pin("2", "~", "passive", 0, -3.81, 90, 1.27)],
       ref_at=(2.54, 1.27), val_at=(2.54, -1.27), names=False)

defsym("C", "C", [poly((-2.032, 0.508), (2.032, 0.508)),
                  poly((-2.032, -0.508), (2.032, -0.508))],
       [pin("1", "~", "passive", 0, 3.81, 270, 2.54),
        pin("2", "~", "passive", 0, -3.81, 90, 2.54)],
       ref_at=(2.54, 1.27), val_at=(2.54, -1.27), names=False)

defsym("LED", "D", [poly((-1.27, -1.27), (-1.27, 1.27)),
                    poly((1.27, 1.27), (1.27, -1.27), (-1.27, 0), (1.27, 1.27)),
                    poly((-1.27, 0), (1.27, 0)),
                    poly((0, 1.27), (-1.27, 2.54)), poly((0.762, 1.27), (-0.508, 2.54))],
       [pin("1", "K", "passive", -3.81, 0, 0),
        pin("2", "A", "passive", 3.81, 0, 180)],
       ref_at=(0, 3.81), val_at=(0, -2.54), names=False)

defsym("D_Schottky", "D", [poly((-1.27, -1.27), (-1.27, 1.27)),
                           poly((1.27, 1.27), (1.27, -1.27), (-1.27, 0), (1.27, 1.27)),
                           poly((-1.27, 0), (1.27, 0)),
                           poly((-1.27, 1.27), (-1.905, 1.27), (-1.905, 0.635)),
                           poly((-1.27, -1.27), (-0.635, -1.27), (-0.635, -0.635))],
       [pin("1", "K", "passive", -3.81, 0, 0),
        pin("2", "A", "passive", 3.81, 0, 180)],
       ref_at=(0, 2.54), val_at=(0, -2.54), names=False)

MOSFET_GFX = [poly((0.254, 2.54), (0.254, -2.54)),          # channel
              poly((-1.27, 1.905), (-1.27, -1.905)),        # gate plate
              poly((-5.08, 0), (-1.27, 0)),                 # gate lead
              poly((0.254, 2.54), (2.54, 2.54), (2.54, 5.08)),      # drain
              poly((0.254, -2.54), (2.54, -2.54), (2.54, -5.08)),   # source
              circ(1.27, 0, 3.81)]
Q_PINS = [pin("1", "G", "input", -7.62, 0, 0),
          pin("2", "S", "passive", 2.54, -7.62, 90),
          pin("3", "D", "passive", 2.54, 7.62, 270)]
defsym("Q_NMOS_GSD", "Q", MOSFET_GFX + [poly((0.254, -1.27), (1.524, -1.27), (0.889, -2.032), (0.254, -1.27), fill="outline")],
       Q_PINS, ref_at=(8.89, 1.27), val_at=(8.89, -1.27), names=False)
defsym("Q_PMOS_GSD", "Q", MOSFET_GFX + [poly((0.254, 1.27), (1.524, 1.27), (0.889, 2.032), (0.254, 1.27), fill="outline")],
       Q_PINS, ref_at=(8.89, 1.27), val_at=(8.89, -1.27), names=False)

defsym("SW_Push", "SW", [circ(-2.032, 0, 0.508), circ(2.032, 0, 0.508),
                         poly((-2.54, 1.27), (2.54, 1.27)), poly((0, 1.27), (0, 3.048)),
                         poly((-2.54, 0), (-5.08, 0)), poly((2.54, 0), (5.08, 0))],
       [pin("1", "1", "passive", -5.08, 0, 0, 0.001),
        pin("2", "2", "passive", 5.08, 0, 180, 0.001)],
       ref_at=(0, 5.08), val_at=(0, -2.54), names=False)

defsym("Crystal", "Y", [rect(-1.143, -2.54, 1.143, 2.54),
                        poly((-1.905, -1.905), (-1.905, 1.905)), poly((1.905, -1.905), (1.905, 1.905)),
                        poly((-3.81, 0), (-1.905, 0)), poly((1.905, 0), (3.81, 0))],
       [pin("1", "1", "passive", -3.81, 0, 0, 0.001),
        pin("3", "3", "passive", 3.81, 0, 180, 0.001),
        pin("2", "GND", "passive", 0, -3.81, 90, 1.27),      # 3225 4-pad: 2 and 4 are the case
        pin("4", "GND", "passive", 0, 3.81, 270, 1.27)],
       ref_at=(5.08, 1.27), val_at=(5.08, -1.27), names=False)

defsym("Battery_Cell", "BT", [poly((-2.54, 1.27), (2.54, 1.27)), poly((-1.27, -0.254), (1.27, -0.254)),
                              poly((-1.27, -0.254), (-1.27, -0.762), (1.27, -0.762), (1.27, -0.254), fill="outline"),
                              poly((0, 1.27), (0, 2.54)), poly((0, -0.762), (0, -2.54)),
                              poly((3.81, 2.54), (3.81, 3.81)), poly((3.175, 3.175), (4.445, 3.175))],
       [pin("1", "+", "passive", 0, 5.08, 270),
        pin("2", "-", "passive", 0, -5.08, 90)],
       ref_at=(8.89, 1.27), val_at=(8.89, -1.27), names=False)

defsym("Pads_2", "J", [rect(-2.54, -2.54, 2.54, 2.54), circ(0, 1.27, 0.635), circ(0, -1.27, 0.635)],
       [pin("1", "1", "passive", 0, 5.08, 270),
        pin("2", "2", "passive", 0, -5.08, 90)],
       ref_at=(5.08, 1.27), val_at=(5.08, -1.27), names=False)

defsym("TC2030_SWD", "J", [rect(-7.62, -8.89, 7.62, 8.89)],
       [pin("1", "VCC", "passive", -10.16, 6.35, 0),
        pin("2", "SWDIO", "passive", -10.16, 3.81, 0),
        pin("3", "NRST", "passive", -10.16, 1.27, 0),
        pin("4", "SWCLK", "passive", -10.16, -1.27, 0),
        pin("5", "GND", "passive", -10.16, -3.81, 0),
        pin("6", "SWO", "passive", -10.16, -6.35, 0)],
       ref_at=(0, 10.16), val_at=(0, -10.16))

defsym("LDO_SOT23", "U", [rect(-7.62, -7.62, 7.62, 5.08)],
       [pin("3", "VIN", "power_in", -10.16, 2.54, 0),
        pin("2", "VOUT", "power_out", 10.16, 2.54, 180),
        pin("1", "GND", "power_in", 0, -10.16, 90)],
       ref_at=(0, 6.35), val_at=(0, -1.27))
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

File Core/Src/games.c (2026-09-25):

#include "games.h"
//----------------------- variables from other files ---------------------------------//

//----------------------- variables from this file -----------------------------------//
int current_brightness = 5; // Initial brightness
int fade_step = 2;          // Brightness step (pulse speed)
// Colors for the 7 classic pieces (plus 0 - empty cell). Format {R, G, B}
const uint8_t colors[8][3] = {
  {0, 0, 0},       // 0: Empty
  {0, 20, 20},     // 1: I - Cyan
  {0, 0, 20},      // 2: J - Blue
  {20, 10, 0},     // 3: L - Orange
  {20, 20, 0},     // 4: O - Yellow
  {0, 20, 0},      // 5: S - Green
  {15, 0, 15},     // 6: T - Purple
  {20, 0, 0}       // 7: Z - Red
};

// Piece array: 7 pieces x 4 rotation states
const uint16_t tetrominoes[7][4] = {
  {0x0F00, 0x2222, 0x00F0, 0x4444}, // I
  {0x44C0, 0x8E00, 0x6440, 0x0E20}, // J
  {0x4460, 0x0E80, 0xC440, 0x2E00}, // L
  {0xCC00, 0xCC00, 0xCC00, 0xCC00}, // O
  {0x06C0, 0x8C40, 0x6C00, 0x4620}, // S
  {0x0E40, 0x4C40, 0x4E00, 0x4640}, // T
  {0x0C60, 0x4C80, 0xC600, 0x2640}  // Z
};

// Tick counter for independent animation
uint8_t game_tick_counter = 0;

//------------------------------ functions -------------------------------------------//
void DrawGame(void) {                               // Updated render function (Y axis direction fixed)
  ClearScreen();
  for (int y = 0; y < MAX_Y; y++) {                 // 1. Draw the "well" (already landed pieces)
	  for (int x = 0; x < MAX_X; x++) {
		  if (gameBoard[y][x] != 0) {
			  uint8_t c_id = gameBoard[y][x];
			  SetPixel(x, y, colors[c_id][0], colors[c_id][1], colors[c_id][2]);
		  }
	  }
  }
  // 2. Draw the currently falling piece
  uint16_t piece = tetrominoes[current_id][current_rotation];
  uint8_t c_id = current_id + 1;
  for (int px = 0; px < 4; px++) {
	  for (int py = 0; py < 4; py++) {
		  if (piece & (1 << (15 - (py * 4 + px)))) {
			  int draw_x = current_x + px;
			  int draw_y = current_y - py;         // Y points up, the piece extends downward

			  if (draw_x >= 0 && draw_x < MAX_X && draw_y >= 0 && draw_y < MAX_Y) {
				  SetPixel(draw_x, draw_y, colors[c_id][0], colors[c_id][1], colors[c_id][2]);
			  }
		  }
	  }
  }
}
// Collision check
uint8_t CheckCollision(int8_t test_x, int8_t test_y, int8_t test_rot) {
  uint16_t piece = tetrominoes[current_id][test_rot];
  for (int px = 0; px < 4; px++) {
	  for (int py = 0; py < 4; py++) {
		  if (piece & (1 << (15 - (py * 4 + px)))) {
			  int board_x = test_x + px;
			  int board_y = test_y - py;
			  if (board_x < 0 || board_x >= MAX_X || board_y < 0) {       // Collision with walls and floor
				  return 1;
			  }
			  if (board_y < MAX_Y && gameBoard[board_y][board_x] != 0) {  // Collision with other blocks (if within the field)
				  return 1;
			  }
		  }
	  }
  }
  return 0;                                                               // Path is clear
}

void LockPiece(void) {                                                    // Lock the piece into the well
  uint16_t piece = tetrominoes[current_id][current_rotation];
  for (int px = 0; px < 4; px++) {
	  for (int py = 0; py < 4; py++) {
		  if (piece & (1 << (15 - (py * 4 + px)))) {
			  int board_x = current_x + px;
			  int board_y = current_y - py;
			  if (board_y >= 0 && board_y < MAX_Y && board_x >= 0 && board_x < MAX_X) {
				  gameBoard[board_y][board_x] = current_id + 1;
			  }
		  }
	  }
  }
}

void ClearLines(void) {                                                   // Remove completed lines
  for (int y = 0; y < MAX_Y; y++) {
	  uint8_t full = 1;
	  for (int x = 0; x < MAX_X; x++) {
		  if (gameBoard[y][x] == 0) {
			  full = 0;
			  break;
		  }
	  }
	  if (full) {                                                         // Shift everything above down one row
		  for (int shift_y = y; shift_y < MAX_Y - 1; shift_y++) {
			  for (int x = 0; x < MAX_X; x++) {
				  gameBoard[shift_y][x] = gameBoard[shift_y + 1][x];
			  }
		  }
		  for (int x = 0; x < MAX_X; x++) {                               // Clear the topmost row
			  gameBoard[MAX_Y - 1][x] = 0;
		  }
		  y--;                                                            // Check the same row again (new blocks fell into it)
	  }
  }
}

// Game over animation
void GameOverAnim(void) {
  // 1. Hide the current (new) piece far off screen
  // so its color doesn't cover the red animation
  current_y = 100;
  // 2. Smoothly fill the screen red from bottom to top
  for (int y = 0; y < MAX_Y; y++) {
	  for (int x = 0; x < MAX_X; x++) {
		  gameBoard[y][x] = 7;
	  }
	  DrawGame();
	  UpdateMatrix();
	  HAL_Delay(50); // Animation slightly sped up
  }

  // 3. Short pause on the fully red screen
  HAL_Delay(500);

  // 4. Clear the well for a new game
  for (int y = 0; y < MAX_Y; y++) {
	  for (int x = 0; x < MAX_X; x++) {
		  gameBoard[y][x] = 0;
	  }
  }
}
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

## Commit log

2026-09-12 Add README, MIT license, and product photo
    Replace the hand-drawn wiring sketch (11.jpg) with a real photo of the
    finished earrings and document the project (modes, hardware, build steps).
2026-09-25 Hardware spec
    [BOM.csv, TetrisEarrings.kicad_sch]
2026-09-25 fixup! Hardware spec
    [BOM.csv, TetrisEarrings.kicad_sch]
2026-09-25 Add KiCad project files for Tetris Earrings: schematic, PCB, scripts, BOM, CPL, and fab outputs
    [BOM.csv, TetrisEarrings-bom.csv, TetrisEarrings.kicad_pcb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]

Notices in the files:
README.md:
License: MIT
